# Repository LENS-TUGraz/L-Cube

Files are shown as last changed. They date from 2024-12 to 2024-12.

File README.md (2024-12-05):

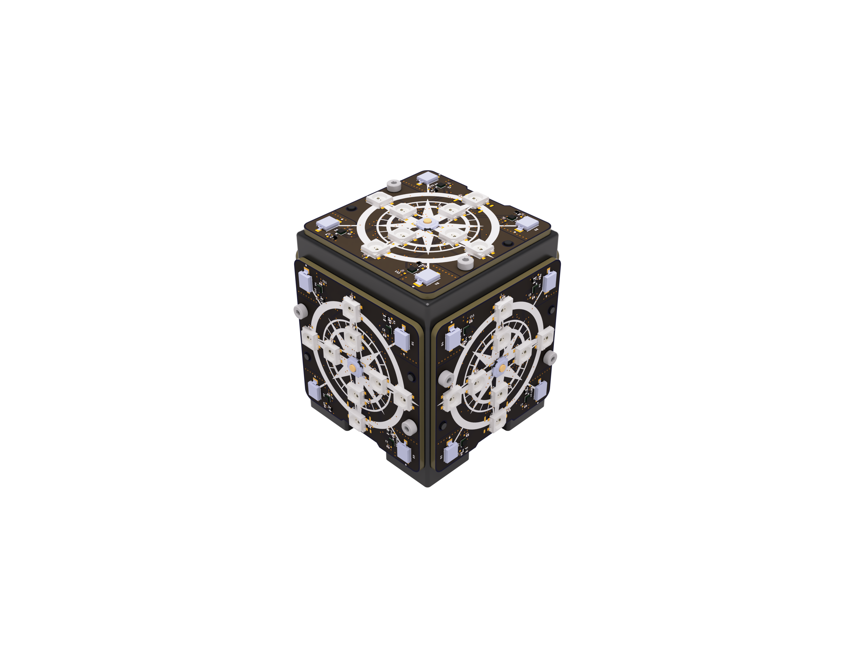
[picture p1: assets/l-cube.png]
LCUBE


# L-Cube Repository

This repository contains the source code for L-CUBE, a low-cost and easy-to-setup localization system with the Lighthouse base stations. The L-Cube consists of five tiles, which can be used in standalone mode via a serial cable connection, or be aggregated in a cube that can interact with other systems via MQTT or serial connection.

In order to build and setup L-CUBE, the hardware folder contains all components for manufacturing, whereas the README from the src folder provides further information about how to use the software.

### Folder structure

| **Folder** | **Description** |
|---|---|
| assets | Metadata |
| hardware | Informations to build your own hardware |
| src | Arduino (c++) sources for the tiles and cube controller |
| tools | Python tools/scripts to interact with the tiles and cubes |

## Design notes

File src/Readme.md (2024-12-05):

# Software Source Folder

## Folder structure

| **Folder** | **Description** |
|---|---|
| calibration_record | Recorder for the calibration data |
| cube_controller_v1_0 | Final cube controller software project (only MQTT credentials and name needs to be changed for every cube) |
| libraries | Contains addapted libraries |
| manufacturing | Test for tile verification after manufacturing the hardware |
| tile_v1_0 | Final tile software project (only I2C adresses need to be changed for every tile) |

# How to use the software sources

All the software fron this folder was developed within the ArduinoIDE. Therfore the setup instructions also base on this program.

## Setup Arduino IDE:

For the cube controller, we used an ESP32S3 development kit, as well as an XIAOESP32C6. The tile has an RP2040 on it.

### 1) ESP32S3 Development Kit:

- Board "ESP32S3 Dev Module" (https://dl.espressif.com/dl/package_esp32_index.json)
- ESP32 version v3.0.7 & v2.0.7
- PubSubClient library v2.8 (https://github.com/knolleary/pubsubclient?tab=readme-ov-file)
- WiFi library v3.0.7 (https://www.arduino.cc/reference/en/libraries/wifi/)
- Wire library v3.0.7 (https://www.arduino.cc/reference/en/language/functions/communication/wire/)

### 2) XIAOESP32C6:

- Board "XIAOESP32_C6"
- ESP32 version v3.0.7
- PubSubClient library v2.8 (https://github.com/knolleary/pubsubclient?tab=readme-ov-file)
- WiFi library v3.0.7 (https://www.arduino.cc/reference/en/libraries/wifi/)
- Wire library v3.0.7 (https://www.arduino.cc/reference/en/language/functions/communication/wire/)

### 3) RP2040:

- Board "Generic RP2040" (https://github.com/earlephilhower/arduino-pico/releases/download/global/package_rp2040_index.json
- TS4231 library (https://www.arduino.cc/reference/en/libraries/ts4231-library/) - *care that we made changes in this library an that it has to be exchanged with ours (in library folder)*
- Adafruit NeoPixel library (https://www.arduino.cc/reference/en/libraries/adafruit-neopixel/)
- Wire library (https://www.arduino.cc/reference/en/language/functions/communication/wire/)
- LittleFS library (https://arduino-pico.readthedocs.io/en/latest/fs.html)

## How to setup the system:

- perform calibration_record for every new base stations once and addapt the calibration_data.h file of the final tile software accordingly - if not already done (only required once or if index number of stations gets changed)
- set WIFI_SSID, WIFI_PASSWORD and MQTT_SERVER on cube controller software to connect to right mqtt server where topics cube_position, cube_forward_vector, cube_up_vector and cube_mode get published
- flash the tiles with their individual I2C_ADDRESS_OFFSET (change in config.h) top tile: index 10, front tile: index 11, right tile: index 12, back tile: index 13, left tile: index 14
- configuration via python scripts are now possible (different scripts depending on how to configure) - requirements.txt file contains required pip installations

## Further things to know:

- tiles need to receive light in order to start (sensor activation needs light in setup-phase)
- calibration_record contains older receiving toplogy (optimal for 1m placement)
- pio pins must be in ascending order (pio function can only aquire ascending order pins)

- pioasm.exe in arduino directory for compiling changed or final .pio to header files that later gets compiled to uf2 file for rp
- cmd call: `pioasm.exe differential_manchester.pio differential_manchester.pio.h`

- if configuration square is not measured precisely and is a bit like a paralellogram, z-coordinate of positioning gets worse
- do not copy data encapsulated by `[]` into configuration file (program skips the line then)
- reflections of wall are rare but possible if hardware is too close to it
- spi-slave on rp2040 is broken - does not tristate (free) data line when communication is to other slave (at least for the first version during development)
- use receiving hardware at least 15 cm below station

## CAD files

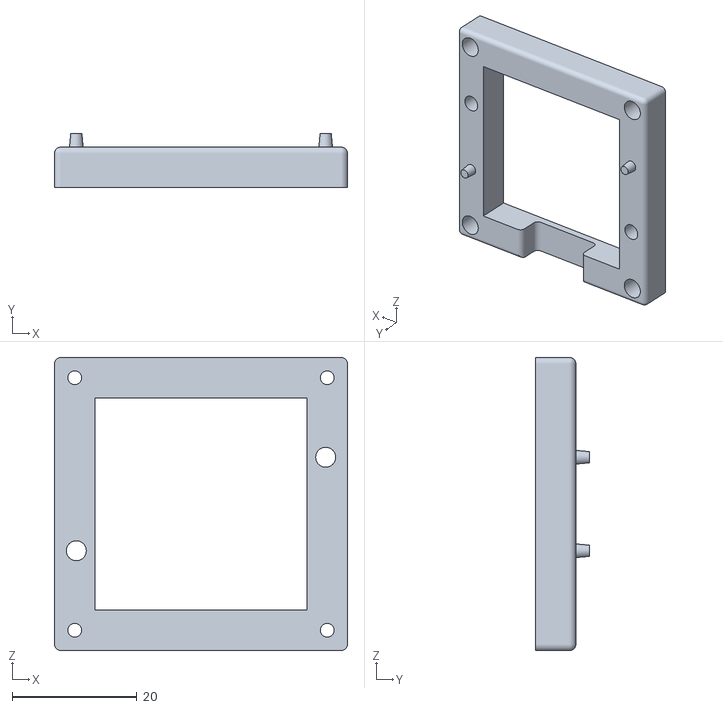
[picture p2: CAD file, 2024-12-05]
hardware/lcube-top.stl
47.0 x 8.70 x 47.0

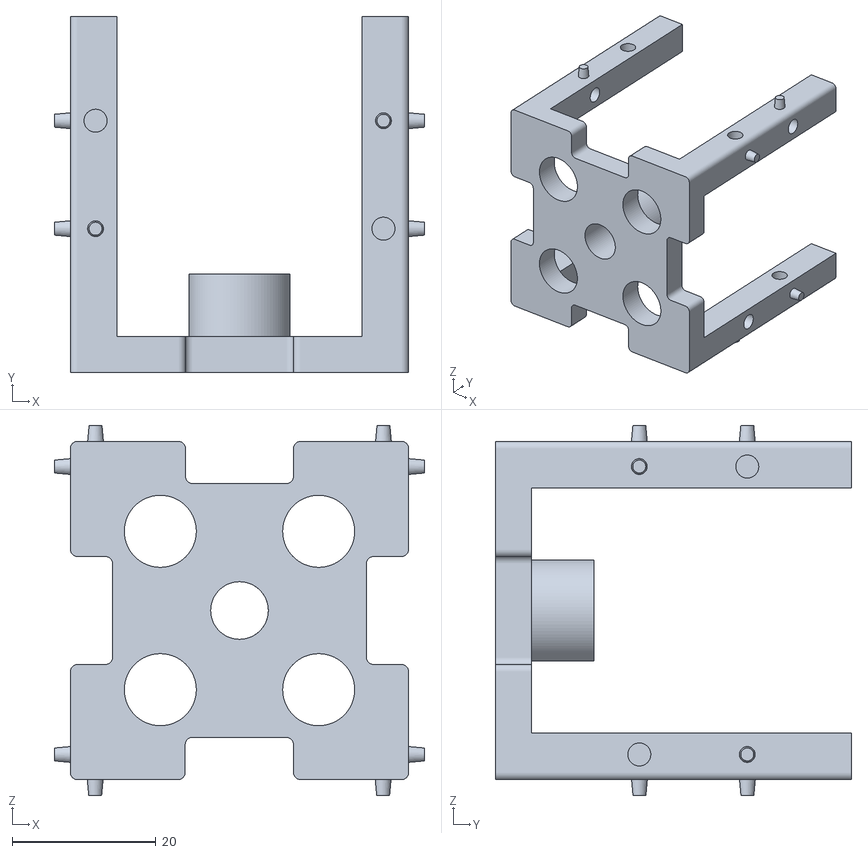
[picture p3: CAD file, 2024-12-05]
hardware/lcube-base.stl
51.4 x 49.5 x 51.4

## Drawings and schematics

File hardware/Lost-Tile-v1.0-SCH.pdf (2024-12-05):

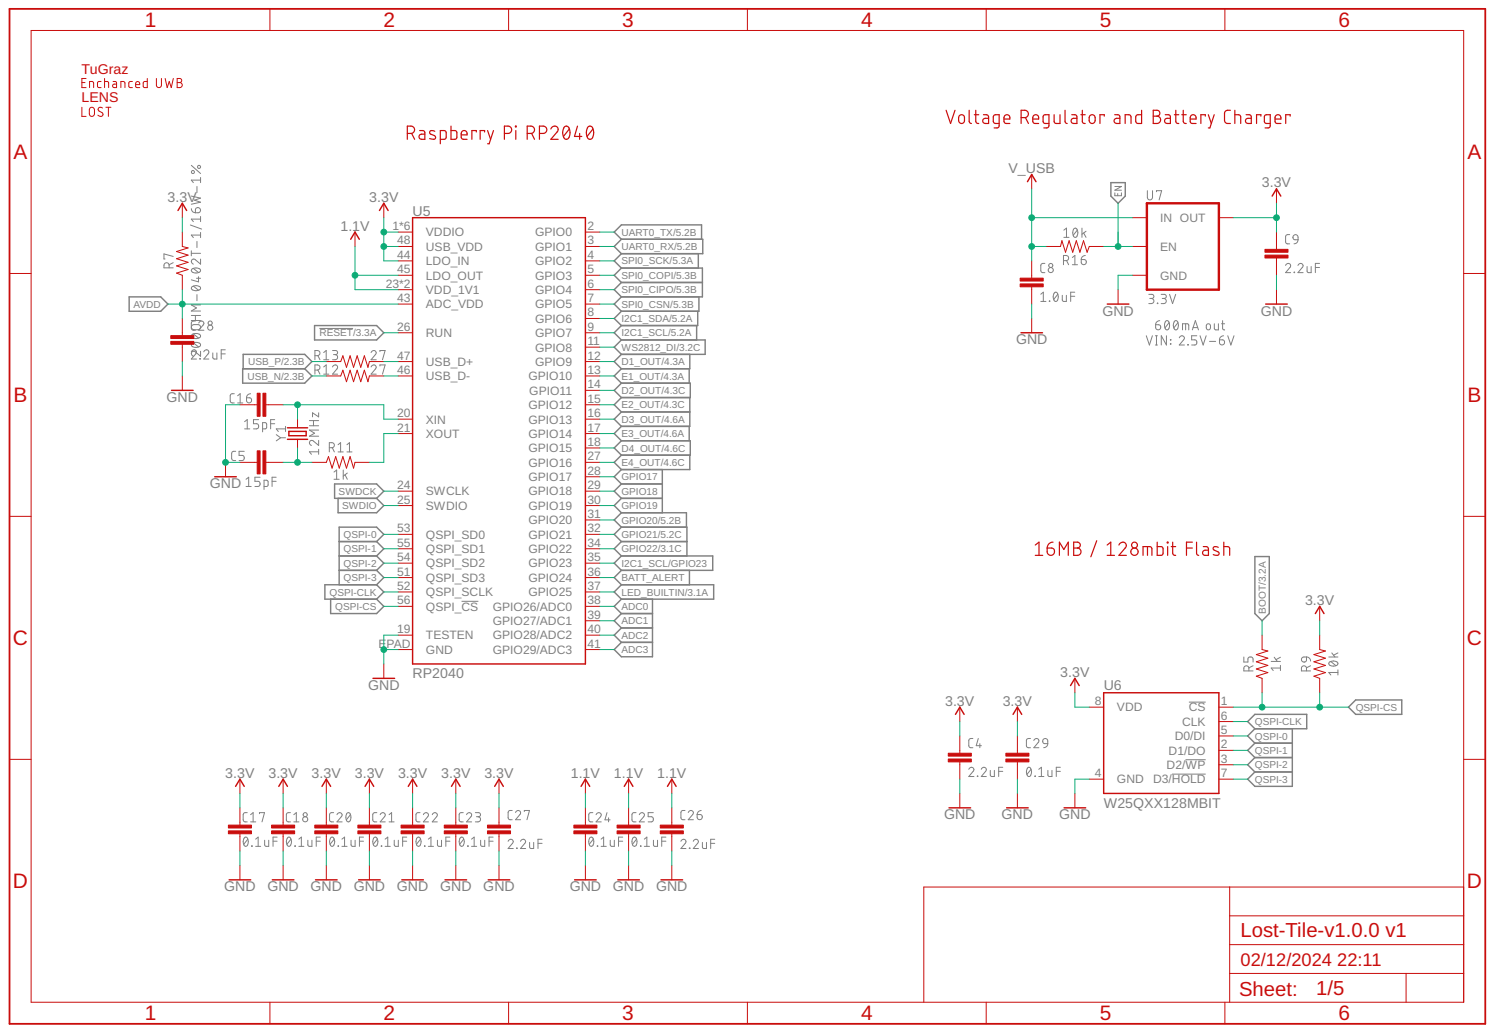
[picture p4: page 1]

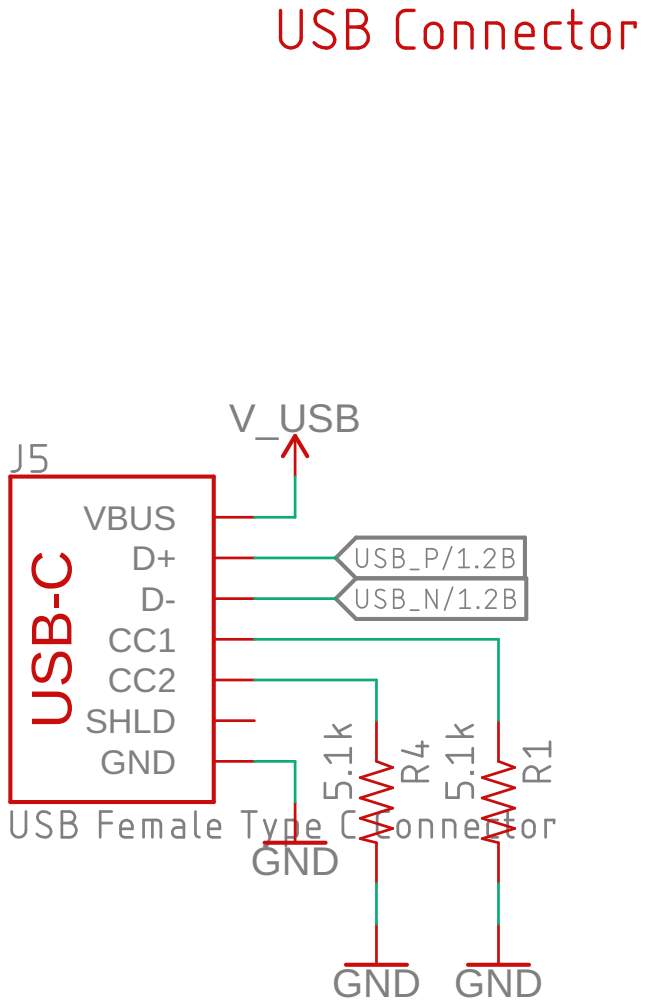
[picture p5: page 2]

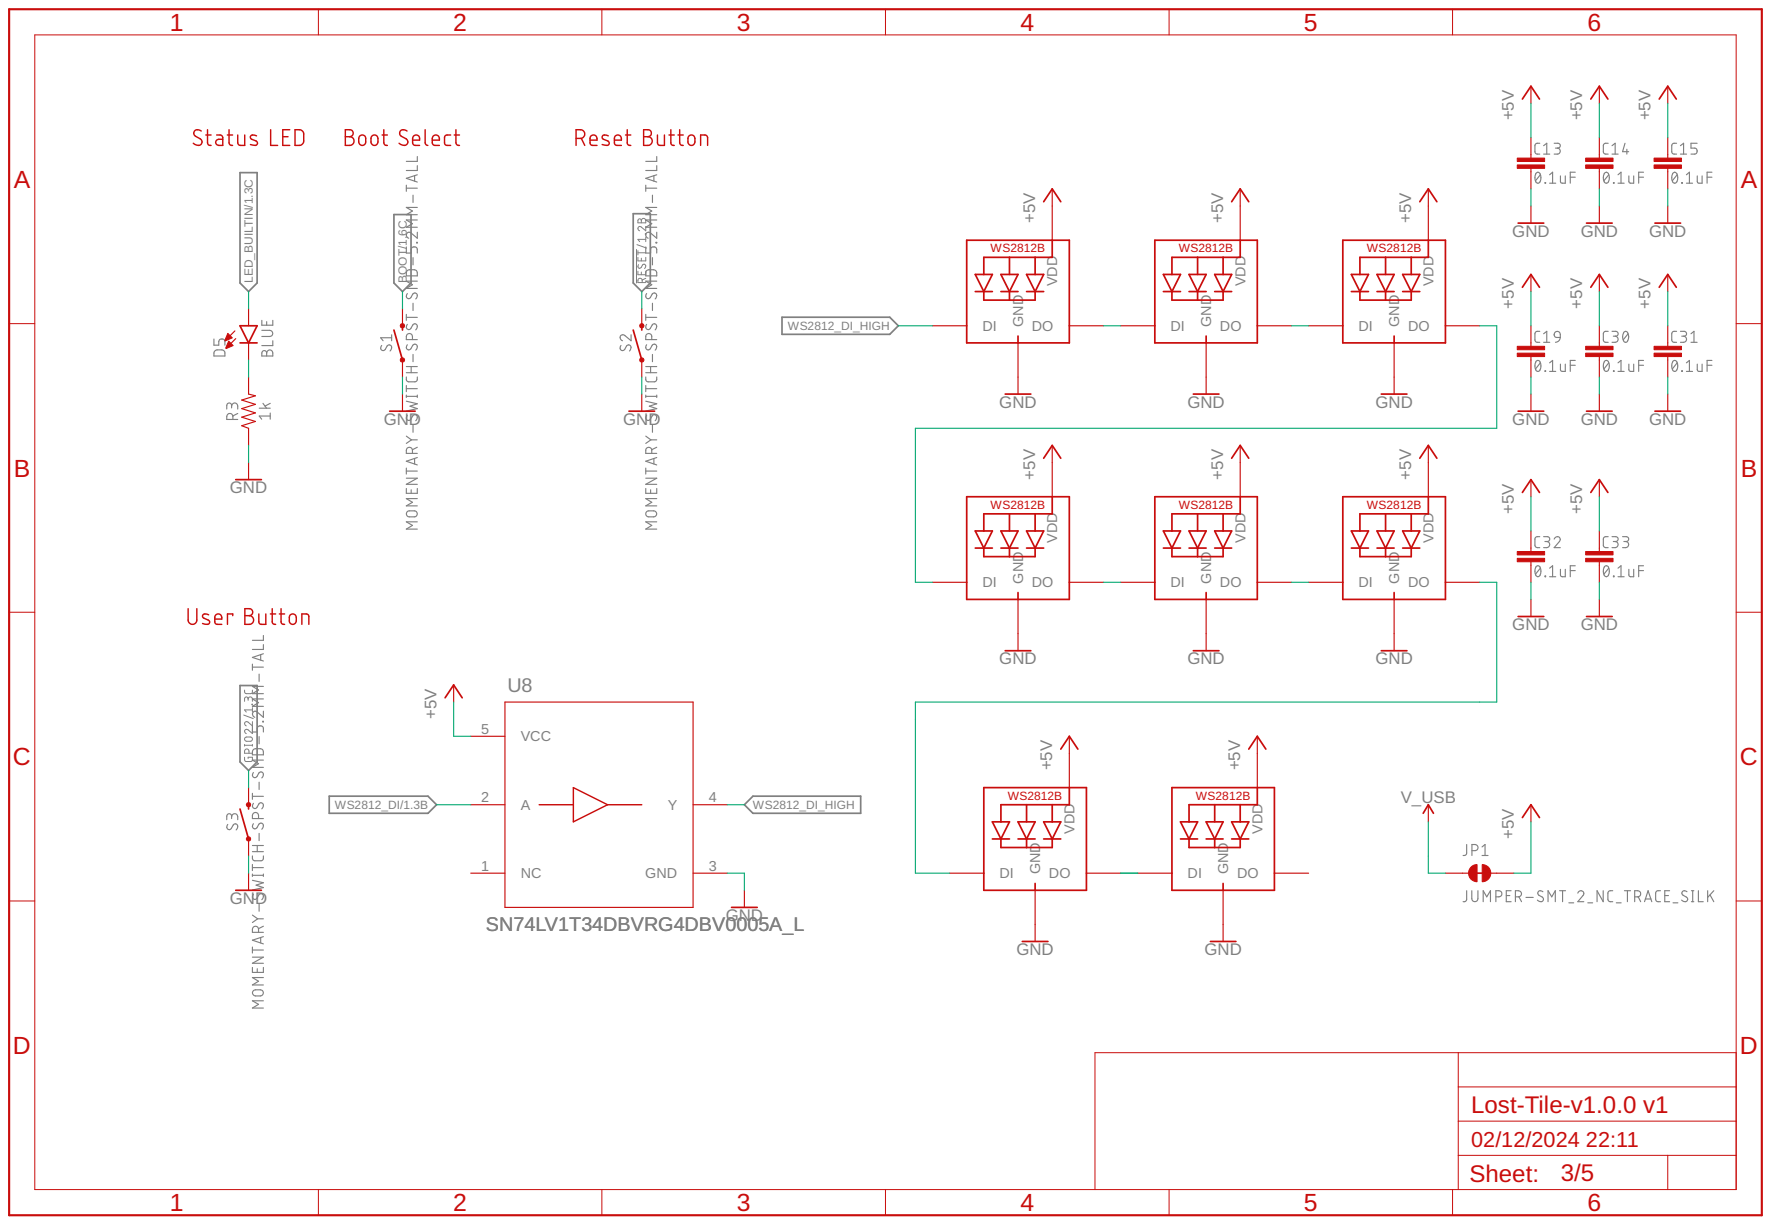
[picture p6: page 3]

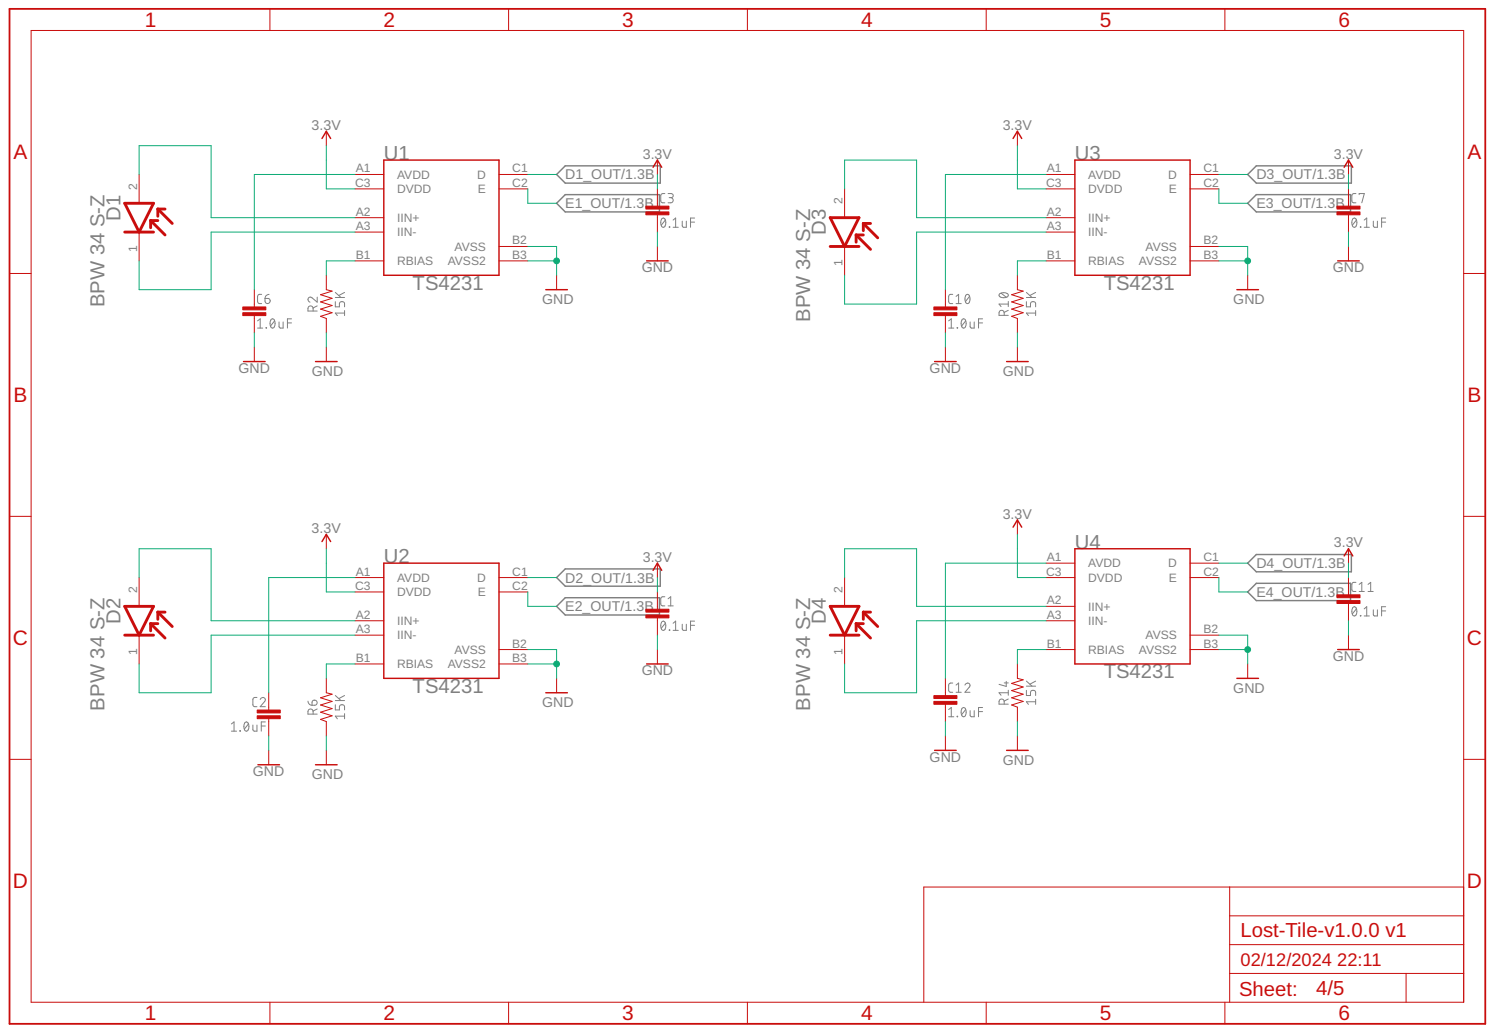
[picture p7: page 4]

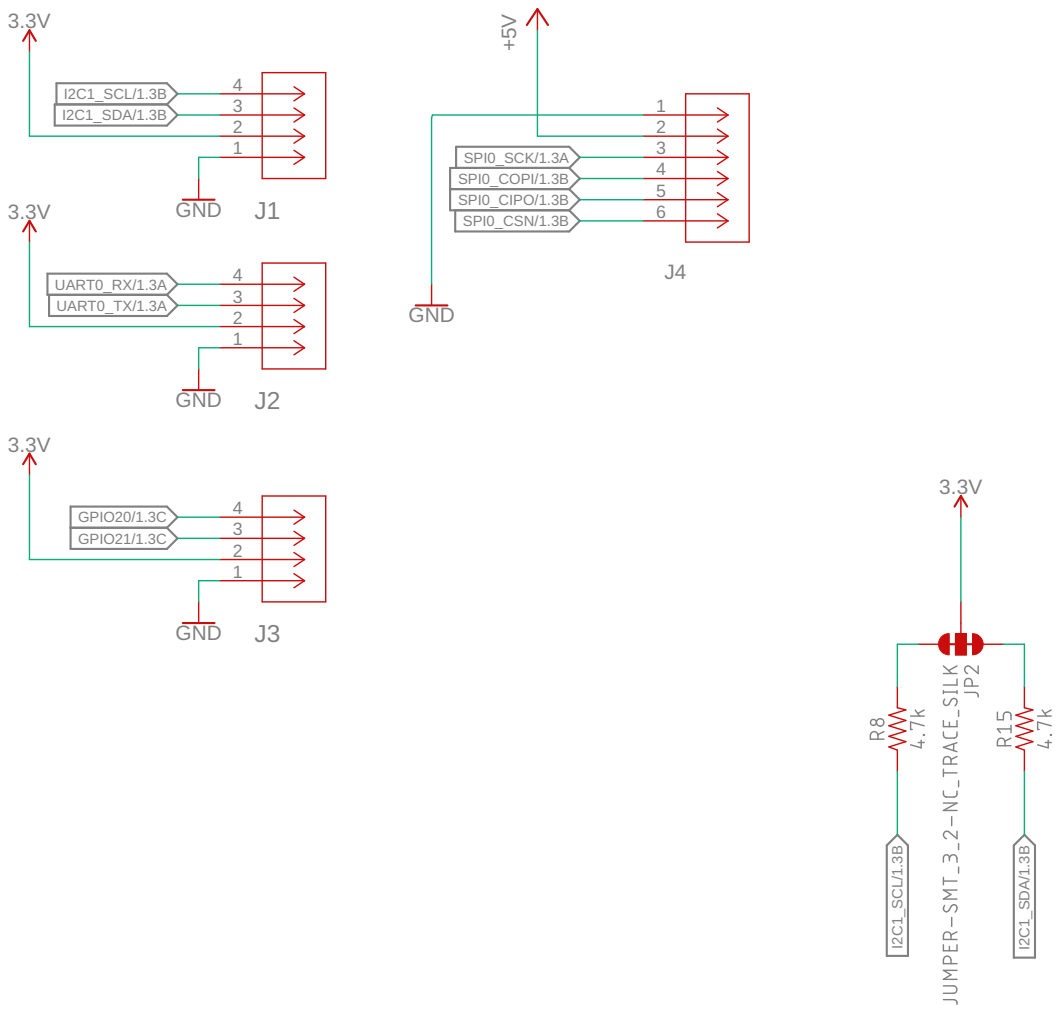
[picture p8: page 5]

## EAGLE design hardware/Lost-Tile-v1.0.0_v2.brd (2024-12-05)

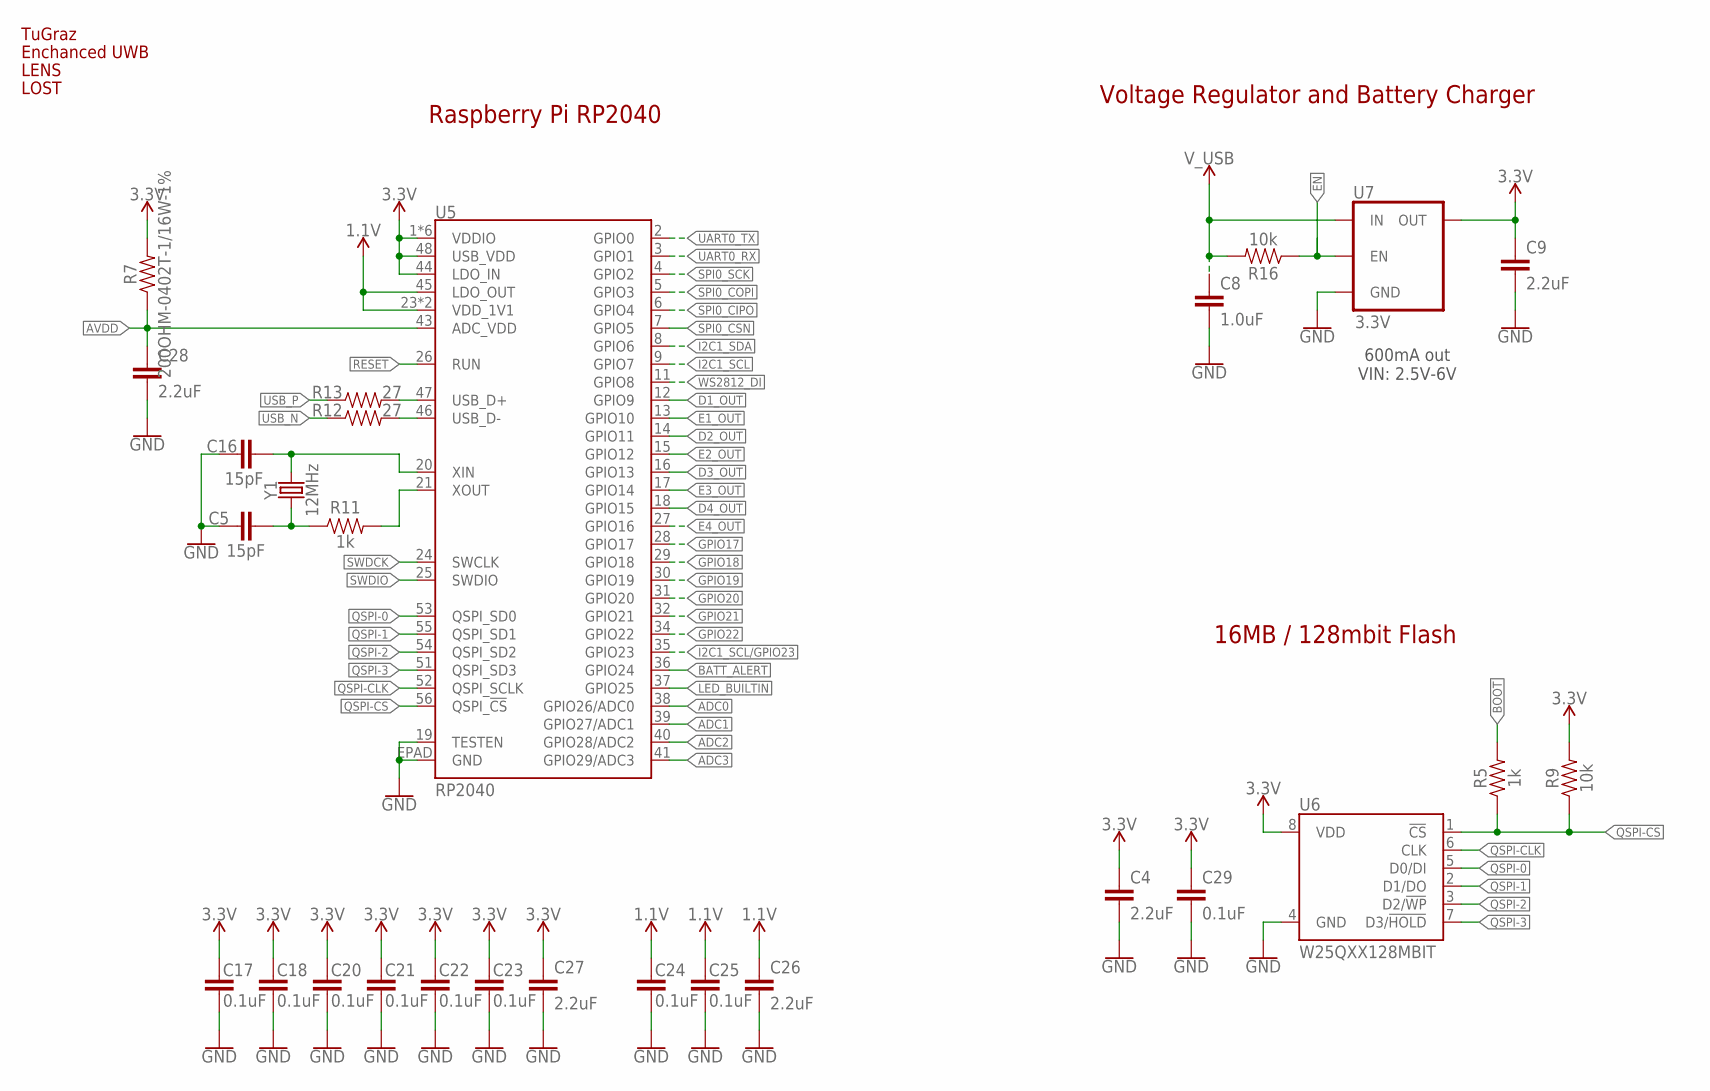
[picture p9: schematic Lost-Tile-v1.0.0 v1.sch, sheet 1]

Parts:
C4, C9, C26, C27, C28: 2.2uF; 0402-TIGHT
C5, C16: 15pF; 0402-TIGHT
C8: 1.0uF; 0402-TIGHT
C17, C18, C20, C21, C22, C23, C24, C25, C29: 0.1uF; 0402-TIGHT
LG1: TU-LOGOSMALL-BICOL; TU-LOGO-SMALL-BICOL
LG2: EUWBBICOL; EUWB_LOGO-BICOL
LG3: LENS
LG4: LOST_LOGO
R5, R11: 1k; 0402-TIGHT
R7: 200OHM-0402T-1/16W-1%; 0402-TIGHT
R9, R16: 10k; 0402-TIGHT
R12, R13: 27; 0402-TIGHT
U5: RP2040; QFN-56
U6: W25QXX128MBIT; WSON-8-6X5-SKINNY_CENTERPAD
U7: 3.3V; SOT23-5
Y1: 12MHz; CRYSTAL-SMD-2X2.5MM

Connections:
1.1V: C24.1, C25.1, C26.1, U5.23 (VDD_1V1), U5.45 (LDO_OUT), U5.50 (VDD_1V1)
3.3V: C4.1, C9.1, C17.1, C18.1, C20.1, C21.1, C22.1, C23.1, C27.1, C29.1, R7.2, R9.2, U5.1 (VDDIO), U5.10 (VDDIO), U5.22 (VDDIO), U5.33 (VDDIO), U5.42 (VDDIO), U5.44 (LDO_IN), U5.48 (USB_VDD), U5.49 (VDDIO), U6.8 (VDD), U7.5 (OUT); also elsewhere on the board
!RESET!: U5.26 (RUN); also elsewhere on the board
ADC0: U5.38 (GPIO26/ADC0)
ADC1: U5.39 (GPIO27/ADC1)
ADC2: U5.40 (GPIO28/ADC2)
ADC3: U5.41 (GPIO29/ADC3)
AVDD: C28.1, R7.1, U5.43 (ADC_VDD)
BATT_ALERT: U5.36 (GPIO24)
BOOT: R5.2; also elsewhere on the board
D1_OUT: U5.12 (GPIO9); also elsewhere on the board
D2_OUT: U5.14 (GPIO11); also elsewhere on the board
D3_OUT: U5.16 (GPIO13); also elsewhere on the board
D4_OUT: U5.18 (GPIO15); also elsewhere on the board
E1_OUT: U5.13 (GPIO10); also elsewhere on the board
E2_OUT: U5.15 (GPIO12); also elsewhere on the board
E3_OUT: U5.17 (GPIO14); also elsewhere on the board
E4_OUT: U5.27 (GPIO16); also elsewhere on the board
EN: R16.1, U7.3 (EN)
GND: C4.2, C5.1, C8.2, C9.2, C16.1, C17.2, C18.2, C20.2, C21.2, C22.2, C23.2, C24.2, C25.2, C26.2, C27.2, C28.2, C29.2, U5.19 (TESTEN), U5.EPAD (GND), U6.4 (GND), U7.2 (GND); also elsewhere on the board
GPIO17: U5.28 (GPIO17)
GPIO18: U5.29 (GPIO18)
GPIO19: U5.30 (GPIO19)
GPIO20: U5.31 (GPIO20); also elsewhere on the board
GPIO21: U5.32 (GPIO21); also elsewhere on the board
GPIO22: U5.34 (GPIO22); also elsewhere on the board
I2C1_SCL: U5.9 (GPIO7); also elsewhere on the board
I2C1_SCL/GPIO23: U5.35 (GPIO23)
I2C1_SDA: U5.8 (GPIO6); also elsewhere on the board
LED_BUILTIN: U5.37 (GPIO25); also elsewhere on the board
unnamed: R11.2, U5.21 (XOUT)
unnamed: C16.2, U5.20 (XIN), Y1.P3 (2)
unnamed: C5.2, R11.1, Y1.P1 (1)
QSPI-0: U5.53 (QSPI_SD0), U6.5 (D0/DI)
QSPI-1: U5.55 (QSPI_SD1), U6.2 (D1/DO)
QSPI-2: U5.54 (QSPI_SD2), U6.3 (D2/!WP!)
QSPI-3: U5.51 (QSPI_SD3), U6.7 (D3/!HOLD!)
QSPI-CLK: U5.52 (QSPI_SCLK), U6.6 (CLK)
QSPI-CS: R5.1, R9.1, U5.56 (QSPI_!CS!), U6.1 (!CS!)
SPI0_CIPO: U5.6 (GPIO4); also elsewhere on the board
SPI0_COPI: U5.5 (GPIO3); also elsewhere on the board
SPI0_CSN: U5.7 (GPIO5); also elsewhere on the board
SPI0_SCK: U5.4 (GPIO2); also elsewhere on the board
SWDCK: U5.24 (SWCLK)
SWDIO: U5.25 (SWDIO)
UART0_RX: U5.3 (GPIO1); also elsewhere on the board
UART0_TX: U5.2 (GPIO0); also elsewhere on the board
USB_F_N: R12.2, U5.46 (USB_D-)
USB_F_P: R13.2, U5.47 (USB_D+)
USB_N: R12.1; also elsewhere on the board
USB_P: R13.1; also elsewhere on the board
V_USB: C8.1, R16.2, U7.1 (IN); also elsewhere on the board
WS2812_DI: U5.11 (GPIO8); also elsewhere on the board

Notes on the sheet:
Raspberry Pi RP2040
16MB / 128mbit Flash
Voltage Regulator and Battery Charger
600mA out VIN: 2.5V-6V

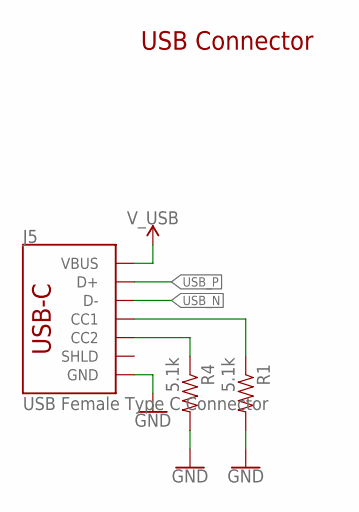
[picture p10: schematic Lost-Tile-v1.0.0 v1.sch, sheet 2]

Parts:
J5: USB Female Type C Connector; USB-C-16P-4LAYER-ISOLATED
R1, R4: 5.1k; 0402-TIGHT

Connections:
GND: J5.GND, J5.GND2 (GND), R1.2, R4.2; also elsewhere on the board
unnamed: J5.A5 (CC1), R1.1
unnamed: J5.B5 (CC2), R4.1
USB_N: J5.A7 (D-), J5.B7 (D-); also elsewhere on the board
USB_P: J5.A6 (D+), J5.B6 (D+); also elsewhere on the board
V_USB: J5.VBUS1 (VBUS), J5.VBUS2 (VBUS); also elsewhere on the board

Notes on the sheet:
USB Connector

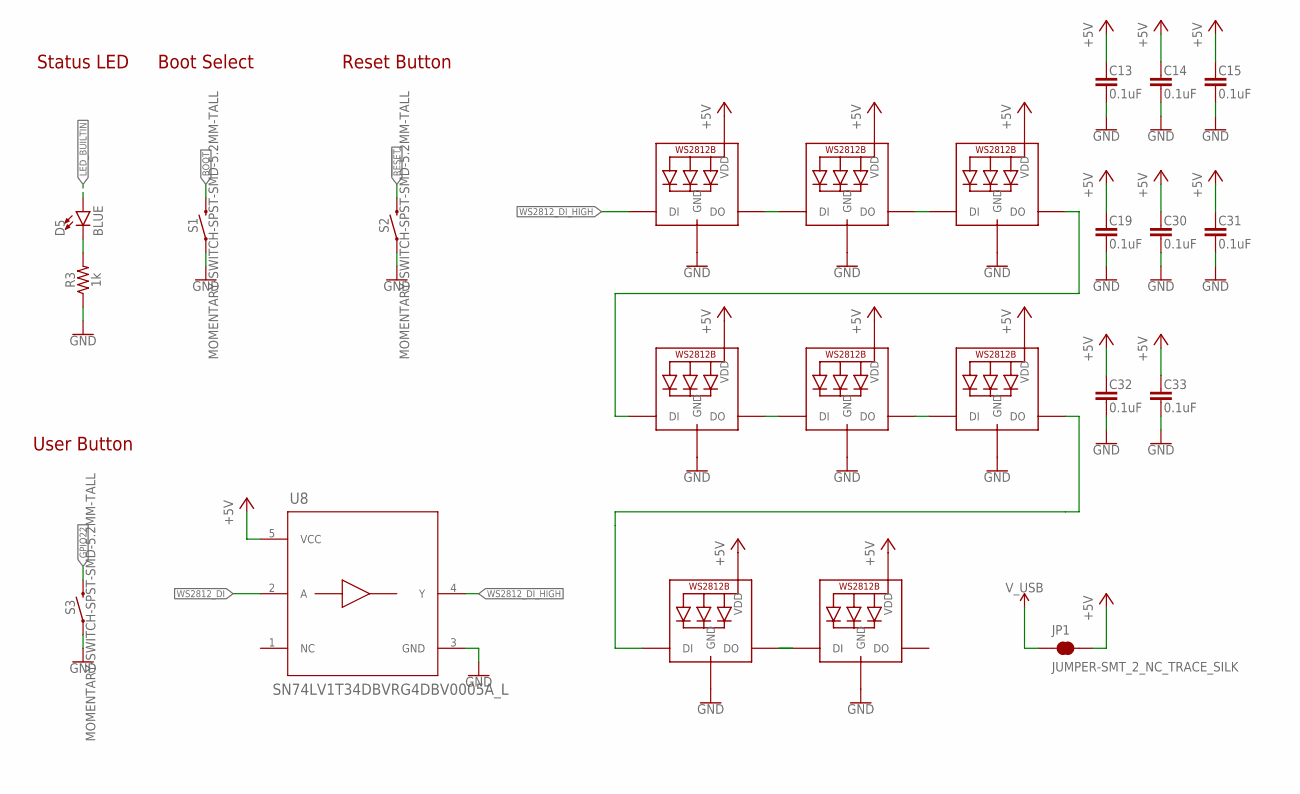
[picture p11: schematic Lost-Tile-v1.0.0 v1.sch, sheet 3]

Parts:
C13, C14, C15, C19, C30, C31, C32, C33: 0.1uF; 0402-TIGHT
D5: BLUE; LED-0603
JP1: JUMPER-SMT_2_NC_TRACE_SILK; SMT-JUMPER_2_NC_TRACE_SILK
LED1, LED2, LED3, LED4, LED5, LED6, LED7, LED8: WS2812B5050; WS2812B
R3: 1k; 0402-TIGHT
S1, S2, S3: MOMENTARY-SWITCH-SPST-SMD-5.2MM-TALL; TACTILE_SWITCH_SMD_5.2MM
U8: SN74LV1T34DBVRG4DBV0005A_L; DBV0005A_L

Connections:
!RESET!: S2.3 (2); also elsewhere on the board
+5V: C13.1, C14.1, C15.1, C19.1, C30.1, C31.1, C32.1, C33.1, JP1.2, LED1.1-VDD (VDD), LED2.1-VDD (VDD), LED3.1-VDD (VDD), LED4.1-VDD (VDD), LED5.1-VDD (VDD), LED6.1-VDD (VDD), LED7.1-VDD (VDD), LED8.1-VDD (VDD), U8.5 (VCC); also elsewhere on the board
BOOT: S1.3 (2); also elsewhere on the board
GND: C13.2, C14.2, C15.2, C19.2, C30.2, C31.2, C32.2, C33.2, LED1.3-GND (GND), LED2.3-GND (GND), LED3.3-GND (GND), LED4.3-GND (GND), LED5.3-GND (GND), LED6.3-GND (GND), LED7.3-GND (GND), LED8.3-GND (GND), R3.1, S1.1, S2.1, S3.1, U8.3 (GND); also elsewhere on the board
GPIO22: S3.3 (2); also elsewhere on the board
LED_BUILTIN: D5.A; also elsewhere on the board
unnamed: D5.C, R3.2
unnamed: LED1.2-DOUT (DO), LED2.4-DIN (DI)
unnamed: LED2.2-DOUT (DO), LED3.4-DIN (DI)
unnamed: LED6.2-DOUT (DO), LED7.4-DIN (DI)
unnamed: LED3.2-DOUT (DO), LED4.4-DIN (DI)
unnamed: LED7.2-DOUT (DO), LED8.4-DIN (DI)
unnamed: LED4.2-DOUT (DO), LED5.4-DIN (DI)
unnamed: LED5.2-DOUT (DO), LED6.4-DIN (DI)
V_USB: JP1.1; also elsewhere on the board
WS2812_DI: U8.2 (A); also elsewhere on the board
WS2812_DI_HIGH: LED1.4-DIN (DI), U8.4 (Y)

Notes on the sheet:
Reset Button
Status LED
Boot Select
User Button

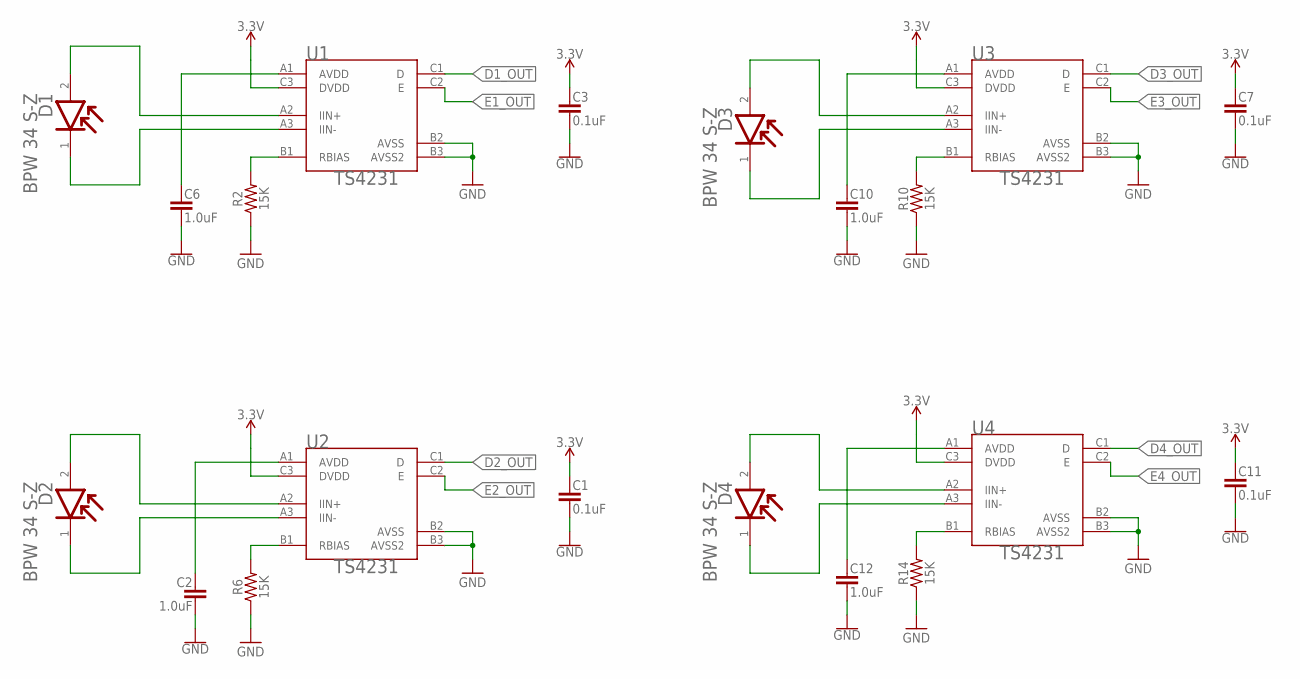
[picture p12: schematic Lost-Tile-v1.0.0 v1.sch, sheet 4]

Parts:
C1, C3, C7, C11: 0.1uF; 0402-TIGHT
C2, C6, C10, C12: 1.0uF; 0402-TIGHT
D1, D2, D3, D4: OSRAM_OPTO_SEMICONDUCTORS_INC._BPW_34_S-ZOSRAM_OP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; OSRAM_OPTO_SEMICONDUCTORS_INC._BPW_34_S-Z_0
R2, R6, R10, R14: 15K; 0402-TIGHT
U1, U2, U3, U4: TRIAD_SEMI_TS4231TRIAD_SEMI_TS4231_0_0; TRIAD_SEMI_TS4231_0

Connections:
3.3V: C1.1, C3.1, C7.1, C11.1, U1.C3 (DVDD), U2.C3 (DVDD), U3.C3 (DVDD), U4.C3 (DVDD); also elsewhere on the board
D1_OUT: U1.C1 (D); also elsewhere on the board
D2_OUT: U2.C1 (D); also elsewhere on the board
D3_OUT: U3.C1 (D); also elsewhere on the board
D4_OUT: U4.C1 (D); also elsewhere on the board
E1_OUT: U1.C2 (E); also elsewhere on the board
E2_OUT: U2.C2 (E); also elsewhere on the board
E3_OUT: U3.C2 (E); also elsewhere on the board
E4_OUT: U4.C2 (E); also elsewhere on the board
GND: C1.2, C2.2, C3.2, C6.2, C7.2, C10.2, C11.2, C12.2, R2.1, R6.1, R10.1, R14.1, U1.B2 (AVSS), U1.B3 (AVSS2), U2.B2 (AVSS), U2.B3 (AVSS2), U3.B2 (AVSS), U3.B3 (AVSS2), U4.B2 (AVSS), U4.B3 (AVSS2); also elsewhere on the board
IIN1+: D1.2 (ANODE), U1.A2 (IIN+)
IIN1-: D1.1 (CATHODE), U1.A3 (IIN-)
IIN2+: D2.2 (ANODE), U2.A2 (IIN+)
IIN2-: D2.1 (CATHODE), U2.A3 (IIN-)
IIN3+: D3.2 (ANODE), U3.A2 (IIN+)
IIN3-: D3.1 (CATHODE), U3.A3 (IIN-)
IIN4+: D4.2 (ANODE), U4.A2 (IIN+)
IIN4-: D4.1 (CATHODE), U4.A3 (IIN-)
unnamed: C6.1, U1.A1 (AVDD)
unnamed: C10.1, U3.A1 (AVDD)
unnamed: C2.1, U2.A1 (AVDD)
unnamed: C12.1, U4.A1 (AVDD)
RBIAS: R2.2, U1.B1 (RBIAS)
RBIAS1: R6.2, U2.B1 (RBIAS)
RBIAS2: R10.2, U3.B1 (RBIAS)
RBIAS3: R14.2, U4.B1 (RBIAS)

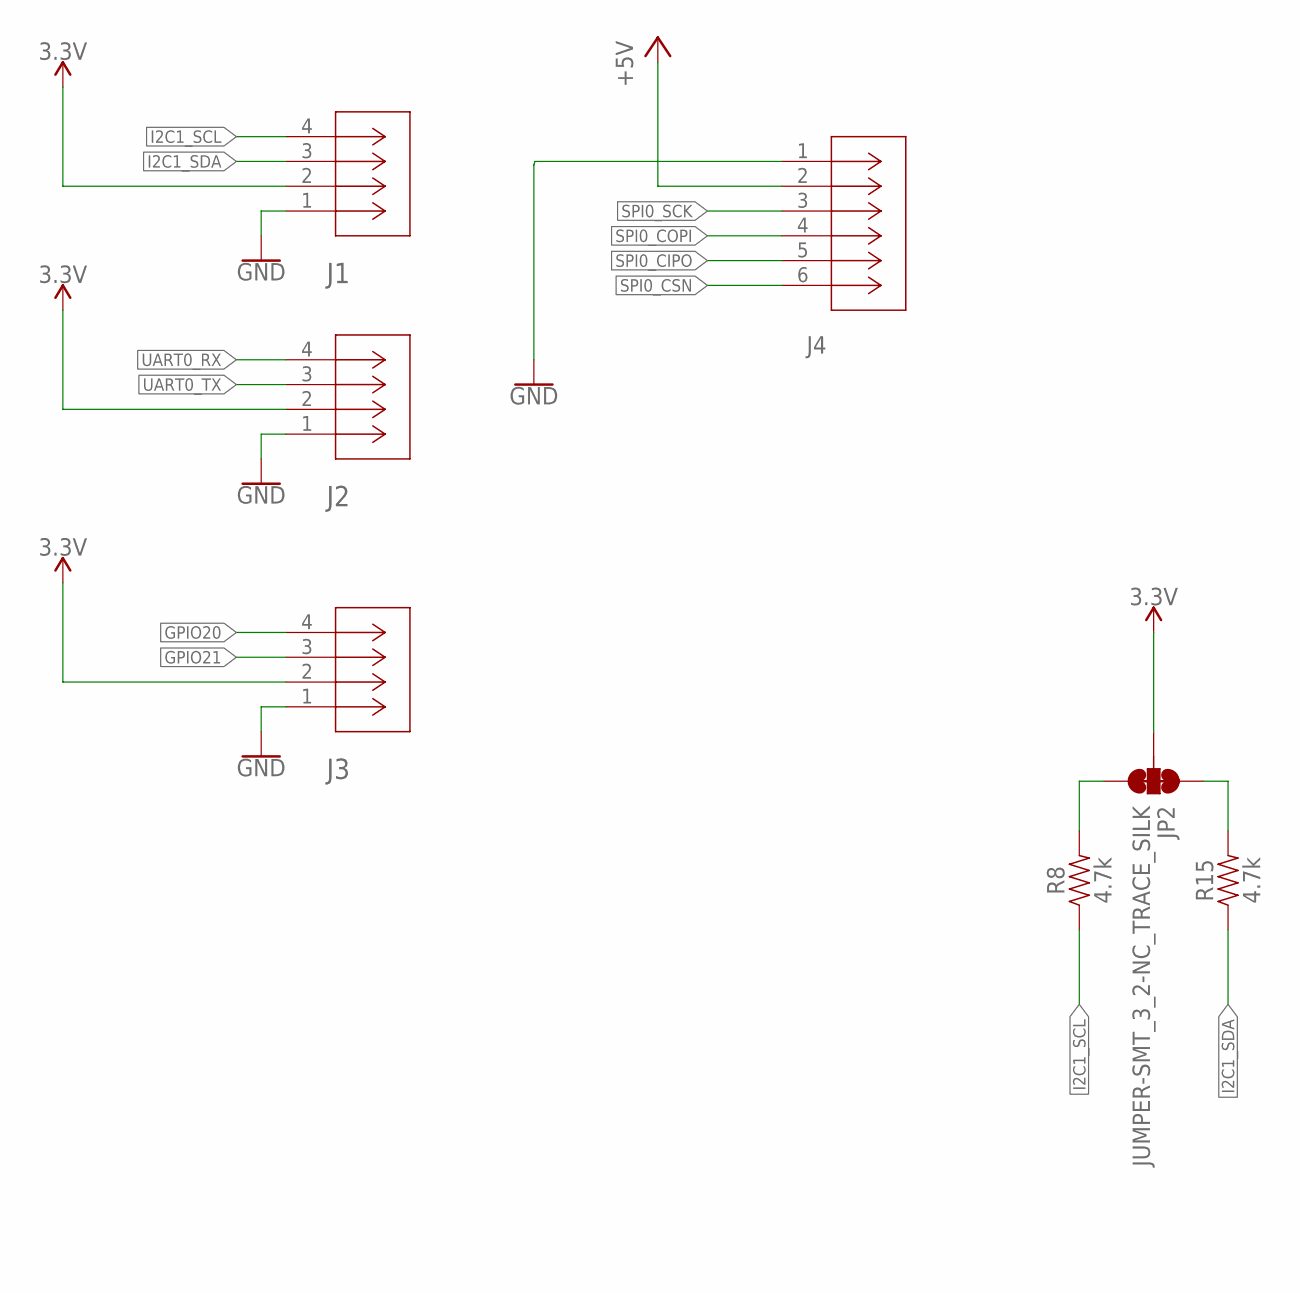
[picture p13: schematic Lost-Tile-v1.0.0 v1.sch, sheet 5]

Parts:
J1, J2, J3: BM04B-SRSS-TBT_(LF)(SN)CONN_BM04B-SRSS-TBT_(LF)(S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; CONN_BM04B-SRSS-TBT_(LF)(SN)_J
J4: BM06B-SRSS-TB(LF)(SN)CONN_BM06B-SRSS-TB_JST; CONN_BM06B-SRSS-TB_JST
JP2: JUMPER-SMT_3_2-NC_TRACE_SILK; SMT-JUMPER_3_2-NC_TRACE_SILK
R8, R15: 4.7k; 0402-TIGHT

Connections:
3.3V: J1.2, J2.2, J3.2, JP2.2; also elsewhere on the board
+5V: J4.2; also elsewhere on the board
GND: J1.1, J2.1, J3.1, J4.1; also elsewhere on the board
GPIO20: J3.4; also elsewhere on the board
GPIO21: J3.3; also elsewhere on the board
I2C1_SCL: J1.4, R8.1; also elsewhere on the board
I2C1_SDA: J1.3, R15.1; also elsewhere on the board
unnamed: JP2.3, R8.2
unnamed: JP2.1, R15.2
SPI0_CIPO: J4.5; also elsewhere on the board
SPI0_COPI: J4.4; also elsewhere on the board
SPI0_CSN: J4.6; also elsewhere on the board
SPI0_SCK: J4.3; also elsewhere on the board
UART0_RX: J2.4; also elsewhere on the board
UART0_TX: J2.3; also elsewhere on the board

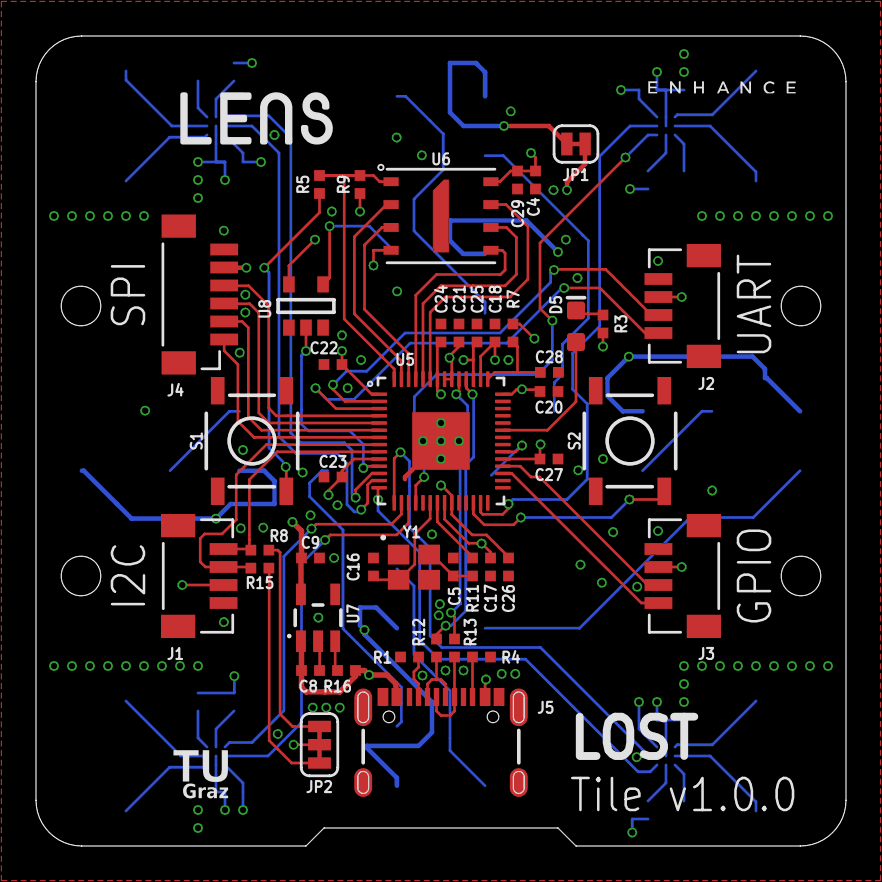
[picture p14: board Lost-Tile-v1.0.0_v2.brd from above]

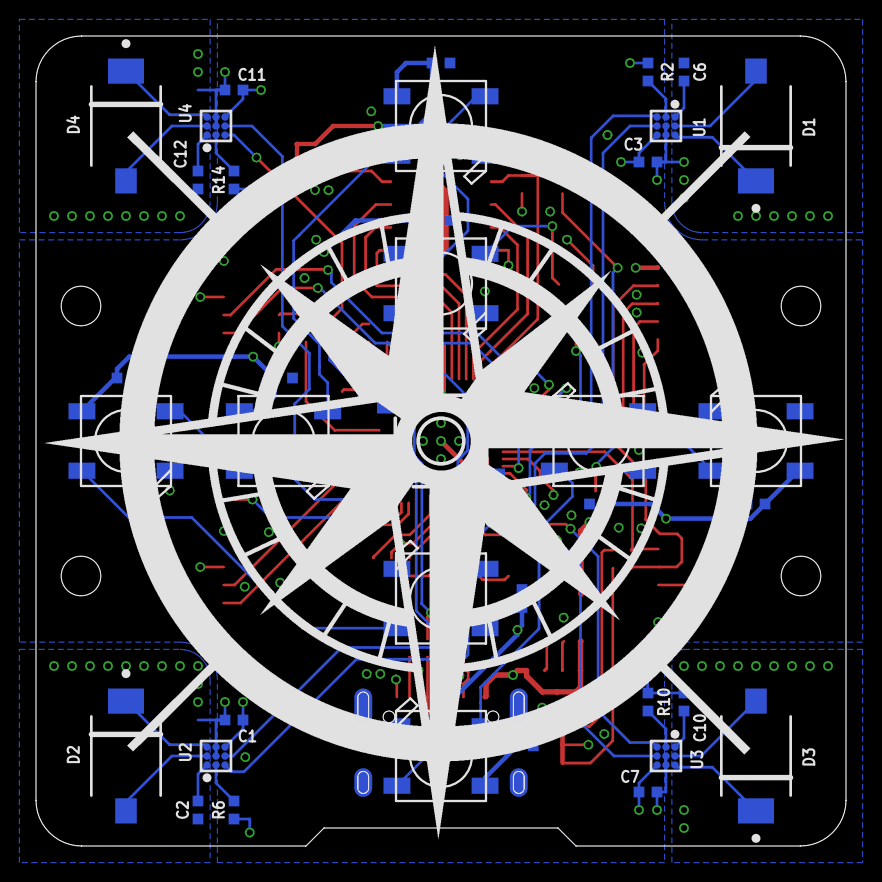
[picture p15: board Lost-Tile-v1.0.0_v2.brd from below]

Board: 4 copper layers, 45.0 x 45.0 mm, 85 parts (38 on the bottom side), 72 nets.

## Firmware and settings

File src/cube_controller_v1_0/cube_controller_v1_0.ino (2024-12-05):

/*
 * L-Cube Cube Controller Software
 *
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
 */

#include <WiFi.h>
#include <PubSubClient.h>
#include <Wire.h>


#include "esp_mmath.h"
#include "esp_config.h"
#include "esp_isr.h"
#include "esp_mqtt.h"
#include "esp_positioning.h"


// - MQTT variables -----------------------------------
// wifi ssid
const char* ssid = WIFI_SSID;
// wifi password
const char* password = WIFI_PASSWORD;
// mqtt server domain
const char* mqtt_server = MQTT_SERVER;
// wifi client class
WiFiClient wifi_client;
// mqtt client class
PubSubClient mqtt_client(wifi_client);

// - positioning variables ----------------------------
// contains position and heading of the lost cube
CubeData cube_data;
// contains position and heading of the tiles
TileData tile_data[NO_TILES];
// timestamp for positioning interval
long last_timestamp = 0;

// - control flow variables ---------------------------
// current operation mode of the esp
enum EspOperationMode esp_operation_mode = normal;
// flag that config data was recieved and needs to be forwarded to tile
uint8_t send_configuration_to_tiles = 0;
// flag that tile wants to send data via i2c
uint8_t i2c_flag[NO_TILES];
// set flag to only send command for configs for one time
uint8_t first_time = 0;
// current mqtt_command to transmit to tile
char mqtt_command = 0;

// - isr variables ------------------------------------
// i2c isr declarations
void (*i2c_isrs[NO_TILES])() = { isr_i2c0, isr_i2c1, isr_i2c2, isr_i2c3, isr_i2c4};

// - pin variables ------------------------------------
// pins for interrupts when a tile wants to send data
uint8_t i2c_com_request_pin[NO_TILES] = {I2C_COM_REQUEST_PINS};

// - i2c variables ------------------------------------
// python MQTT config data that is published
char config_data[MQTT_QUICK_CONFIG_DATA_BYTES + 1] = {0};
// i2c send buffer for config
char i2c_send_buffer[CONFIG_SIZE] = {0};
// i2c receive buffer for config
uint8_t i2c_receive_buffer[MQTT_QUICK_CONFIG_DATA_BYTES +1] = {0};
// i2c index of received byte for config
uint32_t i2c_receive_index = 0;
// positioning updates from tiles are received in this buffer
char i2c_position_update_data[I2C_POSITION_UPDATE_SIZE + 1] = {0};		
// index of current received byte for position updates
uint32_t i2c_position_update_receive_index = 0;

void setup() {
  Serial.begin(115200);

  #if (DBG_SERIAL == 1)
    while(!Serial){}
    Serial.println("[DBG_SERIAL] Serial connection established");
  #endif
  
  for(int i = 0; i < NO_TILES; ++i)
  {
    // set input pins for i2c
    pinMode(i2c_com_request_pin[i], INPUT);
  }

  #if (USE_MQTT == 1)
    // enable external antenna
    pinMode(3, OUTPUT);    // RF switch power on
    digitalWrite(3, LOW);
    pinMode(14, OUTPUT);   // select external antenna
    digitalWrite(14, HIGH);

    setup_wifi();
    mqtt_client.setServer(mqtt_server, 1883);
    mqtt_client.setCallback(callback_mqtt);
  #endif

  // setup i2c
  Wire.begin(I2C_SDA, I2C_SCL, I2C_FREQUENCY); // join i2c bus (address optional for master)

  // attach interrupts for i2c communication request pins
  for(int i = 0; i < NO_TILES; ++i)
  {
    // set interrupts for i2c
    attachInterrupt(digitalPinToInterrupt(i2c_com_request_pin[i]), i2c_isrs[i], FALLING);
  }

  last_timestamp = millis();

  #if (DBG_SERIAL == 1)
    while(!Serial){}
    Serial.println("[DBG_SERIAL] Setup completed");
  #endif
}

#if (SERIAL_MODE == 1)
  // buffer for data
  uint8_t serial_data[MAX_SERIAL_DATA_LENGTH] = {0};
  // index of incomming byte
  uint16_t serial_data_index = 0;
  // for overflow
  uint8_t incoming_serial = 0;
#endif

#if (TEST_MODE == 1)
  // test data from tiles
  uint8_t cube_test_data1[TEST_DATA_SIZE];
  uint8_t cube_test_data2[TEST_DATA_SIZE];
  uint8_t cube_test_data3[TEST_DATA_SIZE];
  uint8_t cube_test_data4[TEST_DATA_SIZE];
  uint8_t cube_test_data5[TEST_DATA_SIZE];

  uint8_t *test_data[5] = {cube_test_data1, cube_test_data2, cube_test_data3, cube_test_data4, cube_test_data5};
#endif


// # loop function ####################################################################################################################
void loop() {

  #if (USE_MQTT == 1)
    // asure mqtt connection
    if (!mqtt_client.connected()) {
      reconnect_mqtt();
    }

    // call mqtt internal loop
    mqtt_client.loop();
    // until here, mqtt needs up to 3ms, so should be fine (included sending bs_data)
  #endif
  
  #if (SERIAL_MODE == 1)
    // get serial data (configuration) if available
    if(Serial.available() > 0)
    {
      serial_data_index = 0;
      // receive line and check if it was data
      while(Serial.available() > 0)
      {
        // read line and check if it is data
        serial_data[serial_data_index] = Serial.read();

        if(serial_data[serial_data_index] == '\n')
        {
          // line read - check if config data ('d' at beginning and 50 chars long)
          // check for 50, as it gets incremented later
          if((serial_data[0] == 'd') && (serial_data_index == 50))
          {
            // it's config data, forward it
            for(uint8_t i = 0; i < NO_TILES; ++i)
            {
              // send configuration to tile
              Wire.beginTransmission(I2C_ADDRESS_OFFSET + i);
              Wire.write(serial_data, CONFIG_SIZE);
              Wire.endTransmission();
            }
          }

          // stop command
          if(serial_data[0] == 's')
          {
            // it's stop command, forward it
            char stop = 's';
            Serial.println("stp_signal");
            // send stop command
            for(uint8_t i = 0; i < NO_TILES; ++i)
            {
              Wire.beginTransmission(I2C_ADDRESS_OFFSET + i);
              Wire.write(stop);
              Wire.endTransmission();
            }
          }

          // if config data and \n in it, use it as data
          if(!((serial_data[0] == 'd') && (serial_data_index < 50)))
          {
            // use \n as data
            break;
          }
        }
        
        if(serial_data_index >= 51)
        {
          // don't let buffer overflow happen
          // read rest of buffer and do nothing with it
          while(Serial.available() > 0)
          {
            incoming_serial = Serial.read();
          }
          break;
        }
        else
        {
          serial_data_index++;
        }
      }
    }
  #endif

  // perform different modes of operation
  switch(esp_operation_mode)
  {
  // ==========================================================================================================
    case normal:
      // perform positioning
      for(uint8_t tile_index = 0; tile_index < NO_TILES; ++tile_index)
      {
        // receive or send tile data if required
        if(i2c_flag[tile_index] == 1)
        {
          // check if all tiles can send data (only required after assembly)
          //Serial.println(tile_index);
          //Serial.println(i2c_position_update_data[0]);

          // reset i2c request flag
          i2c_flag[tile_index] = 0;
          // receive positioning data from tile
          #if (DBG_I2C == 1)
            //Serial.print("[DBG_I2C] Starting transaction to tile ");
            //Serial.println(tile_index);
          #endif

          // perform i2c transfer
          // receive data via i2c
          Wire.requestFrom(I2C_ADDRESS_OFFSET + tile_index, I2C_POSITION_UPDATE_SIZE);
          i2c_position_update_receive_index = 0;
          while (Wire.available())
          {
            // receive i2c data
            i2c_position_update_data[i2c_position_update_receive_index] = Wire.read();
            i2c_position_update_receive_index++;
          }
						 
          // u for crossing update, v for sweeping update
          if((i2c_position_update_data[0] != 'u') && (i2c_position_update_data[0] != 'v'))
          {
            // no valid data, bus error
            continue;
          }

          #if (TEST_MODE == 1)
            // for testing, data is forwarded to serial here
            memcpy(test_data[tile_index], i2c_position_update_data, TEST_DATA_SIZE);
            
            // crossing update
            if(i2c_position_update_data[0] == 'u')
            {
              test_data[tile_index][0] = tile_index + 20;
            }
            // sweeping update
            if(i2c_position_update_data[0] == 'v')
            {
              test_data[tile_index][0] = tile_index;
            }
            
            
            Serial.write((byte*)test_data[tile_index], TEST_DATA_SIZE);
            Serial.println("");
            
            // could also send data to pc via mqtt, but cable is more reliable
            // mqtt_client.publish("t", test_data[tile_index], TEST_DATA_SIZE);
          #endif

          memcpy((void*)tile_data[tile_index].tile_position, (void*)(&i2c_position_update_data[1]), 12);
          memcpy((void*)tile_data[tile_index].forward_vector, (void*)(&i2c_position_update_data[13]), 12);
          memcpy((void*)tile_data[tile_index].up_vector, (void*)(&i2c_position_update_data[25]), 12);
          
          // set sweeping or crossing (u for crossing, v for sweeping)
          if(i2c_position_update_data[0] == 'u')
          {
            tile_data[tile_index].is_crossing = 1;
          }
          if(i2c_position_update_data[0] == 'v')
          {
            tile_data[tile_index].is_crossing = 0;
          }

          // set timestamp
          tile_data[tile_index].last_update = millis();

          #if (DBG_I2C == 1)
            Serial.print("[DBG_I2C] Received data from tile ");
            Serial.println(tile_index);
            Serial.println("[DBG_I2C] Position");
            print_vector(tile_data[tile_index].tile_position);
            Serial.println("[DBG_I2C] Forward Vector");
            print_vector(tile_data[tile_index].forward_vector);
            Serial.println("[DBG_I2C] Up Vector");
            print_vector(tile_data[tile_index].up_vector);
          #endif
        }
      }

      if((millis() - last_timestamp) > UPDATE_PERIOD)
      {
        // calculate global position for cube
        update_global_position();
        last_timestamp = millis();
      }
      break;

  // ==========================================================================================================
    case config_i2c:
      // config only possible with top tile
      if(first_time == 1)
      {
        #if (DBG_I2C == 1)
          Serial.print("[DBG_I2C] send command via i2c: ");
          Serial.println(mqtt_command);
        #endif

        first_time = 0;

        // send mqtt_command to tile
        Wire.beginTransmission(I2C_ADDRESS_OFFSET + CONFIG_TILE_INDEX);
        Wire.write(mqtt_command);
        Wire.endTransmission();
      }

      // tile wants to send config data
      if(i2c_flag[CONFIG_TILE_INDEX] == 1)
      {
        // receive config data from tile
        #if (DBG_I2C == 1)
          Serial.println("[DBG_I2C] Starting receiving normal config data from top tile");
        #endif

        // receive data via i2c
        Wire.requestFrom(I2C_ADDRESS_OFFSET + CONFIG_TILE_INDEX, MQTT_NORMAL_CONFIG_DATA_BYTES);
        i2c_receive_index = 0;

        while (Wire.available())
        {
          // receive i2c data
          i2c_receive_buffer[i2c_receive_index] = Wire.read();
          i2c_receive_index++;
        }

        // early return when received command is "ready"
        if(i2c_receive_buffer[0] == 'r')
        {
          // ready command -> publish it
          #if (DBG_I2C == 1)
            Serial.println("[DBG_I2C] Publish ready command");
          #endif
          mqtt_client.publish("r","1");

          i2c_flag[CONFIG_TILE_INDEX] = 0;
          break;
        }

        // received data is config data - copy to outgoing mqtt stream
        memcpy((void*)config_data, (void*)(i2c_receive_buffer), MQTT_NORMAL_CONFIG_DATA_BYTES);
        
        #if (DBG_I2C == 1)
          Serial.println("[DBG_I2C] Received config data");
          Serial.println("[DBG_I2C] Command");
          Serial.println((char)i2c_receive_buffer[0]);
          Serial.println("[DBG_I2C] Station");
          Serial.println((uint8_t)i2c_receive_buffer[1]);
          Serial.println("[DBG_I2C] Azimuth & Elevation");
          Serial.print("[");
          Serial.print(*((float*)(&i2c_receive_buffer[2])));
          Serial.print(",");
          Serial.print(*((float*)(&i2c_receive_buffer[6])));
          Serial.println("]");
        #endif

        // transfer data to pc via MQTT
        // p for python data
        mqtt_client.publish("p", (uint8_t*)config_data, MQTT_NORMAL_CONFIG_DATA_BYTES);

        i2c_flag[CONFIG_TILE_INDEX] = 0;
      }
      break;

  // ==========================================================================================================
    case quick_config_i2c:
      // flag for only forward command once
      if(first_time == 1)
      {
        #if (DBG_I2C == 1)
          Serial.print("[DBG_I2C] send command via i2c: ");
          Serial.println(mqtt_command);
        #endif
        first_time = 0;

        // send mqtt_command to tile
        Wire.beginTransmission(I2C_ADDRESS_OFFSET + CONFIG_TILE_INDEX);
        Wire.write(mqtt_command);
        Wire.endTransmission();
      }

      // tile now records data, wait for interrupts and then forward data to python
      if(i2c_flag[CONFIG_TILE_INDEX] == 1)
      {
        // receive config data from tile
        #if (DBG_I2C == 1)
          Serial.println("[DBG_I2C] Starting receiving quick config data from top tile");
        #endif

        // receive data via i2c
        Wire.requestFrom(I2C_ADDRESS_OFFSET + CONFIG_TILE_INDEX, MQTT_QUICK_CONFIG_DATA_BYTES);
        i2c_receive_index = 0;

        while (Wire.available())
        {
          // receive i2c data
          i2c_receive_buffer[i2c_receive_index] = Wire.read();
          i2c_receive_index++;
        }

        // copy received config data to outgoing mqtt stream
        memcpy((void*)config_data, (void*)(i2c_receive_buffer), MQTT_QUICK_CONFIG_DATA_BYTES);
        
        #if (DBG_I2C == 1)
          Serial.println("[DBG_I2C] Received config data");
          Serial.println("[DBG_I2C] Command");
          Serial.println((char)i2c_receive_buffer[0]);
          Serial.println("[DBG_I2C] Station");
          Serial.println((uint8_t)i2c_receive_buffer[1]);
          Serial.println("[DBG_I2C] Azimuths & Elevations (a1, e1, a2, e2, ...");
          for(int i = 0; i < 8; ++i)
          {
            Serial.println(*((float*)(&i2c_receive_buffer[2 + (i * 4)])));
          }
        #endif

        #if (USE_MQTT == 1)
          // transfer data to pc via MQTT
          // p for python data
          mqtt_client.publish("p", (uint8_t*)config_data, MQTT_QUICK_CONFIG_DATA_BYTES);
        #endif

        i2c_flag[CONFIG_TILE_INDEX] = 0;
      }
      
      break;

  // ==========================================================================================================
    case send_config_data:
      if(send_configuration_to_tiles == 1)
      {
        // send data to tiles
        for(uint8_t i = 0; i < NO_TILES; ++i)
        {
          // send mqtt_command to tile
          Wire.beginTransmission(I2C_ADDRESS_OFFSET + i);
          Wire.write((uint8_t*)i2c_send_buffer, CONFIG_SIZE);
          Wire.endTransmission();
        }
        send_configuration_to_tiles = 0;
      }
      break;

// ==========================================================================================================
    case send_stop_command:
      // send stop command to tiles and continue in normal mode
      #if (DBG_I2C)
        Serial.println("[DBG_I2C] send stop command to tile");
      #endif
      char stop = 's';

      // send stop command
	    for(uint8_t i = 0; i < NO_TILES; ++i)
      {
        Wire.beginTransmission(I2C_ADDRESS_OFFSET + i);
        Wire.write(stop);
        Wire.endTransmission();
	    }

      esp_operation_mode = normal;
      break;
  }
}

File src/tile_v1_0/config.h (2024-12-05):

/*
 * L-Cube Tile Software
 *
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
 */

// includeguard
#ifndef CONFIG_
#define CONFIG_

// - STANDALONE -------------------------------------------
// tile is connected via serial and cable to pc
// with this, configuration and positionioning can be done and sent to pc
#define USE_SERIAL 0
// data gets printed in a format that it can be used for the visualization
#define PRINT_DATA_VISUALIZATION 0

// - CUBE MODE  -------------------------------------------
// disable USE_SERIAL and PRINT_DATA_VISUALIZATION
// set I2C_ADDRESS_OFFSET accordingly and then flash individual tiles

// - GENERAL ----------------------------------------------
// Divides the brightnes of the leds (2 -> 100%/2 = 50% brightness) (3->33%) (4->25%)
#define DARKNESS_FACTOR 100
// it is physically impossible to receive beams farer than 7-8m away from a base station - drop calcualted position
#define DISTANCE_LIMIT 10
// dirty limit+update limit becomes latency!
// amount of last received beams are allowed for positioning calculation -> 5 means if the beam was received in the last 5 rounds (1sec), it gets used for calculating
#define DIRTY_LIMIT 10
// contains the update cycles within which the position data of one sensor is used for the general position and heading -> (UPDATE_LIMIT*20ms) is the time how old the data is allowed to be
// set this to 0 when using sweeping only to get the best update rate for fast movements
// we use all sensor position data calculated within 100ms for crossing (improves update rate because of non ideal 100% beam reception)
#define UPDATE_LIMIT 5
// number of maximal possible photodiodes
#define MAX_PHOTODIODES 4
// number of photodiodes in use (cannot exceed MAX_PHOTODIODES)
#define NO_PHOTODIODES 4
// highest base station number
#define MAX_BASE_STATIONS 16
// time to receive light once for configuration of ts4231 [ms]
#define LIGHT_TIMEOUT 500
// minimal possible difference between two beams
#define BEAM_INDEX_DIFFERENCE 15000

// - DBG --------------------------------------------------
// wait before starting the system until serial connection to pc is established for dbg messages
#define DBG_SERIAL 0
// for more information about pio and configuration of ts4231
#define DBG_SENSORS 0
// print values of crossing calculation
#define DBG_CROSSING 0
// print values of sweeping calculation
#define DBG_SWEEPING 0
// if position of the tile should be printed
#define DBG_POSITION 0
// if heading of the tile should be printed
#define DBG_HEADING 0
// show new configurations that are received
#define DBG_CONFIG 0
// show config file storage debug output
#define DBG_CONFIG_FILE 0
// show debug messages of i2c
#define DBG_I2C 0
// debug calibration 
#define DBG_CALIB 0

// - SERIAL -----------------------------------------------
// size of buffer where config that is received via serial is stored
#define SERIAL_CONFIG_DATA_SIZE 51


// - I2C --------------------------------------------------
// i2c tile address of tile 0 (0-10, 1-11, 2-12, 3-13, 4-14)
#define I2C_ADDRESS_OFFSET 10
// amount of sent data bytes for quick config
#define QUICK_CONFIG_DATA_BYTES 34
// amount of sent data bytes for normal config
#define NORMAL_CONFIG_DATA_BYTES 10
// size of configuration line
#define CONFIG_SIZE 50
// 100000, 400000, or 1000000 with only 90% right reception
#define I2C_FREQUENCY 400000
// size to send to esp32 when tile has new position
#define UPDATE_SIZE 37 


// - BS CONFIGURATION -------------------------------------
// print the loaded positioning data from file
#define SHOW_LOADED_CONFIG_DATA 0
// maxumum number of values in a line of the config file
#define MAX_SUBSTRINGS_CONFIG 12
// configuration logging time of each position for normal configuration
#define CONFIG_LOGGING_TIME 5000
// defines the array size of the positions that are logged -> has to be at least 50 for every second + some spare space if something goes wrong
#define CONFIG_LOGGING_POSITIONS 50
// delay until config file gets written permanently after receiving a new configuration
#define CONFIG_FILE_DELAY 1000


// - LEDS -------------------------------------------------
// leds on top of tile
#define NUM_LEDS 8
// indices of leds on the array are the following: [0,1,6,7,4,5,2,3] (they are wired counterclockwise)
// led blink time in [ms]
#define LED_DELAY_TIME 200


// - INTERNAL ---------------------------------------------
#define DF DARKNESS_FACTOR
// colors of leds
#define COL_WHITE  pixels.Color(255/DF, 255/DF, 255/DF)
#define COL_YELLOW pixels.Color(255/DF,   0/DF, 255/DF)
#define COL_GREEN  pixels.Color(  0/DF, 255/DF,   0/DF)
#define COL_BLUE   pixels.Color(  0/DF,   0/DF, 255/DF)
#define COL_PINK   pixels.Color(255/DF,   0/DF, 255/DF)
#define COL_RED    pixels.Color(255/DF,   0/DF,   0/DF)
#define COL_OFF    pixels.Color(  0/DF,   0/DF,   0/DF)
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

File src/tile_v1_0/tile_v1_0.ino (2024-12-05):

/*
 * L-Cube Tile Software
 *
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
 */

#include <hardware/pio.h>
#include "differential_manchester.pio.h"
#include "lookup.h"
#include "crossing.h"
#include "sweeping.h"
#include "isr.h"
#include "sensor_config.h"
#include "config.h"
#include "mmath.h"
#include "file_system.h"
#include "positioning.h"
#include "i2c.h"
#include "bs_configuration.h"
#include <Adafruit_NeoPixel.h>
#include <Wire.h>


// class for ws2812 leds on top (neopixels)
Adafruit_NeoPixel pixels = Adafruit_NeoPixel(NUM_LEDS, PIN_LEDS, NEO_GRB + NEO_KHZ800);

// - I2C ------------------------------------------------------------------------------------------
// i2c buffer which was received
char i2c_receive_buffer[CONFIG_SIZE + 1] = {0};
// i2c buffer that is sent to cube
char i2c_send_buffer[QUICK_CONFIG_DATA_BYTES + 1] = {0};
// i2c buffer that is sent for position updates
char i2c_update_data[UPDATE_SIZE + 1] = {0};
// i2c address of tile
uint8_t i2c_address = I2C_ADDRESS_OFFSET;
// flag for i2c message was received
uint8_t i2c_received = 0;

// - PHOTODIODES ----------------------------------------------------------------------------------
// flags to set in ISR and handle in loop()
uint8_t e_flag[MAX_PHOTODIODES] = { 0 };
// isr declarations
void (*isrs[MAX_PHOTODIODES])() = { isr_e0, isr_e1, isr_e2, isr_e3};
// data and envelope pins of the receiving sensors (photodiode+ts4231)
uint8_t photodiode_d_pin[MAX_PHOTODIODES] = {D_PINS};
uint8_t photodiode_e_pin[MAX_PHOTODIODES] = {E_PINS};
// rp2040 contains two pio blocks (pio0,pio1) with four state machines each which share a memory of 32 instructions
// we only use pio1 entirely -> pio0,sm0 is used by adafruit neopixel
PIO pio = pio1;
// indexes of state machines of pio1
uint pio_state_machines[MAX_PHOTODIODES] = {0, 1, 2, 3};
// buffer for received stream for decoding
uint32_t rx_buffer[2] = { 0 };
// stream for lookup
uint32_t lookup_stream[2] = { 0 };
// beam for lookup (constructed out of lookup stream)
uint64_t beam = 0;
// lfsr index from lookup
uint32_t lfsr_index;
// lfsr from lookup
uint8_t lfsr;
// represents index of station where beam was emitted
uint8_t beam_station_index = 0;
// counter for fresh beams that are received
int count_dirty = 0;
// counter of successful decodes
uint32_t count = 0;
// individual counter of successful decodes
uint32_t individual_count[4] = { 0 };
// timestamp for beam reception
unsigned long count_timestamp = 0;
// difference of saved and received beam
uint32_t beam_difference = 0;

// - POSITIONING ----------------------------------------------------------------------------------
// timestamp for position calculation
unsigned long last_timestamp;
// data representing the decoded beams recevied by the sensors
SensorData sensor_data[NO_PHOTODIODES];
// position of the photodiodes
SensorPosition sensor_position[NO_PHOTODIODES];
// position of the middle of the tile
vec3d tile_position = {0};
// vector that points from middle to front side of the tile (from usb connector to the point between d4&d1)
vec3d forward_vector = {0};
// vector that points 90 degrees to the plane which is constructed by the 4 photodiodes
vec3d up_vector = {0};
// vector that points from middle to the left side of the tile
vec3d side_vector = {0};

// - CONFIGURATION --------------------------------------------------------------------------------
// flag for storing config permanent in file
uint8_t rewrite_file = 0;
// timestamp for storing file
unsigned long file_timestamp = 0;
// station positions and heading
// stations at origin, looking to x direction when no config file present
vec3d station_positions[MAX_BASE_STATIONS] = { {0,0,0}, { 0, 0, 0 } };
mat3x3 station_orientations[MAX_BASE_STATIONS] = { { 1, 0, 0, 0, 1, 0, 0, 0, 1 }, { 1, 0, 0, 0, 1, 0, 0, 0, 1 } };
// station index of the received config
uint8_t config_station_index = 0;
// flag that quick configuration data for the station has already been sent
uint8_t config_done[MAX_BASE_STATIONS] = {0};
// last received command of normal config
uint8_t last_received_command_number = 0;
// normal configuration step
enum ConfigurationSteps config_step = wait_next_position;
// if current config mode is quick config, used for length of sent data packet via i2c
uint8_t quick_config_mode = 0;

// - SERIAL ---------------------------------------------------------------------------------------
// serial incomming character (c - config)
char incoming_serial = 0;

// - CONTROL --------------------------------------------------------------------------------------
// operation mode of tile
enum TileOperationModes operation_mode = normal;

// normal mode: 5 for max range
// calib mode: 10-30 for best reception (about half a meter away!)
int skipped_bits = 10;
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

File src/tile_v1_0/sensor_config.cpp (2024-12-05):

/*
 * L-Cube Tile Software
 *
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
 */

#include <ts4231.h>
#include "config.h"
#include "sensor_config.h"
#include <hardware/pio.h>
#include "differential_manchester.pio.h"
#include <Arduino.h>

// pins of photodiodes
extern uint8_t photodiode_d_pin[MAX_PHOTODIODES];
extern uint8_t photodiode_e_pin[MAX_PHOTODIODES];
// sensor classes
TS4231* sensors[MAX_PHOTODIODES];
// flag that photodiodes are configured
uint8_t photodiode_configured[MAX_PHOTODIODES] = {0};
// indexes of state machines from pio
extern uint pio_state_machines[MAX_PHOTODIODES];

// configure sensors to receive beams
void configure_sensors()
{
  uint8_t configuration_missing = 1;
  uint8_t config_result = 0;

  // construct device classes
  for(int i = 0; i < NO_PHOTODIODES; ++i)
  {
    sensors[i] = new TS4231(photodiode_e_pin[i], photodiode_d_pin[i]);
  }

  while(configuration_missing)
  {
    // configure the photodiodes
    for(int i = 0; i < NO_PHOTODIODES; ++i)
    {
      if(photodiode_configured[i] == 0)
      {
        // wait for light first, as this is the way how to configure
        if (sensors[i]->waitForLight(LIGHT_TIMEOUT))
        {
          #if (DBG_SENSORS == 1)
            Serial.print("[DBG_SENSORS] Light for Sensor ");
            Serial.print(i);
            Serial.println(" DETECTED");
          #endif
          
          // care: use modified ts4231 library, as other methods might not work because
          // rpi sets the output pin to low if it gets configured as output
          // this violate timings with the normal ts4231 lib
          config_result = sensors[i]->configDevice();

          // when a fail state occurs, just try again, otherwise set flag
          if(config_result == CONFIG_PASS)
          {
            photodiode_configured[i] = 1;
          }

          #if (DBG_SENSORS == 1)
            // print configuration status
            Serial.print("[DBG_SENSORS] Sensor ");
            Serial.print(i);
            switch (config_result) 
            {
              case CONFIG_PASS:
                Serial.println(" Configuration SUCCESS");
                break;
              case BUS_FAIL: // unable to resolve state of TS4231 (3 samples of the bus signals resulted in 3 different states)
                Serial.println(" Configuration Unsuccessful - BUS_FAIL");
                break;
              case VERIFY_FAIL: // configuration read value did not match configuration write value, run configuration again
                Serial.println(" Configuration Unsuccessful - VERIFY_FAIL");
                break;
              case WATCH_FAIL: //verify succeeded but entry into WATCH mode failed, run configuration again
                Serial.println(" Configuration Unsuccessful - WATCH_FAIL");
                break;
              default: //value returned was unknown
                Serial.println(" Program Execution ERROR");
                break;
            }
          #endif
        }
        else
        {
          #if (DBG_SENSORS == 1)
            // no light detection
            Serial.print("[DBG_SENSORS] Light Sensor ");
            Serial.print(i);
            Serial.println(" TIMEOUT");
          #endif
        }
      }
    }

    // check if all photodiodes are configured
    configuration_missing = 0;
    for(int i = 0; i < NO_PHOTODIODES; ++i)
    {
      if(photodiode_configured[i] == 0)
      {
        configuration_missing = 1;
      }
    }
  }
}


// setup pio for receiving
void setup_pio()
{
  #if (DBG_SENSORS == 1)
    Serial.println("[DBG_SENSORS] Before adding program");
  #endif

  uint offset_rx1 = 0;

  if(pio_can_add_program(pio1, &differential_manchester_rx_program))
  {
    offset_rx1 = pio_add_program(pio1, &differential_manchester_rx_program);
    #if (DBG_SENSORS == 1)
      Serial.print("[DBG_SENSORS] Receive PIO1 program loaded at ");
      Serial.println(offset_rx1);
    #endif
  }
  else
  {
    #if (DBG_SENSORS == 1)
      Serial.println("[DBG_SENSORS] Not able to add programm memory of pio1");
    #endif
  }

  // configure state machines, set bit rate to 6 Mbps
  // 125MHz default clock (even if arduino selected 133MHz) -> dividing by 125 makes 1MHz as timebase, times 16 to have 16 cycles for one bit
  // -> times 6 for 6 MHz
  float clock_divider = 125.f / (16 * 6);
  
  // init pio program on state machine -> only that line should then be done more often (each sm has own pc)
  for(int i = 0; i < NO_PHOTODIODES; ++i)
  {
    differential_manchester_rx_program_init(pio1, pio_state_machines[i], offset_rx1, photodiode_d_pin[i], photodiode_e_pin[i], clock_divider);
  }

  #if (DBG_SENSORS == 1)
    Serial.print("[DBG_SENSORS] PIO loaded");
  #endif
}

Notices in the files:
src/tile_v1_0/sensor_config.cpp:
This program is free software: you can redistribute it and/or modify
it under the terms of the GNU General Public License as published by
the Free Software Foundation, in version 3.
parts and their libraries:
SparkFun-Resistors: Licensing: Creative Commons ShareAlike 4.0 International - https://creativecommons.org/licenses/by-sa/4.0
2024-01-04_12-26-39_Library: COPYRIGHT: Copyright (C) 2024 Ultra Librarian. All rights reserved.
